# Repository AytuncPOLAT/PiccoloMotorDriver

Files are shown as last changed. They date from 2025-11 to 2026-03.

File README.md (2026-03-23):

# PiccoloMotorDriver

Yet another open source servo motor driver designed using Kicad, based on STM32H723 MCU and DRV8316 integrated 3-phase motor driver.

Firmware can be found here (under development): https://github.com/AytuncPOLAT/PiccoloMotorDriverFw

All the subsystems have been tested

| Subsystem | Test Status |
| --- | --- |
| FDCAN | :heavy_check_mark: |
| RS485 | :heavy_check_mark: |
| USB | :heavy_check_mark: |
| Debug UART | :clock9: |
| SWD | :heavy_check_mark: |
| Ext. Encoder  | :heavy_check_mark: |
| Ext. Analog | :heavy_check_mark: |
| LEDs | :heavy_check_mark: |
| J9 GPIOs | :clock9: |
| DRV8316 | :heavy_check_mark: |

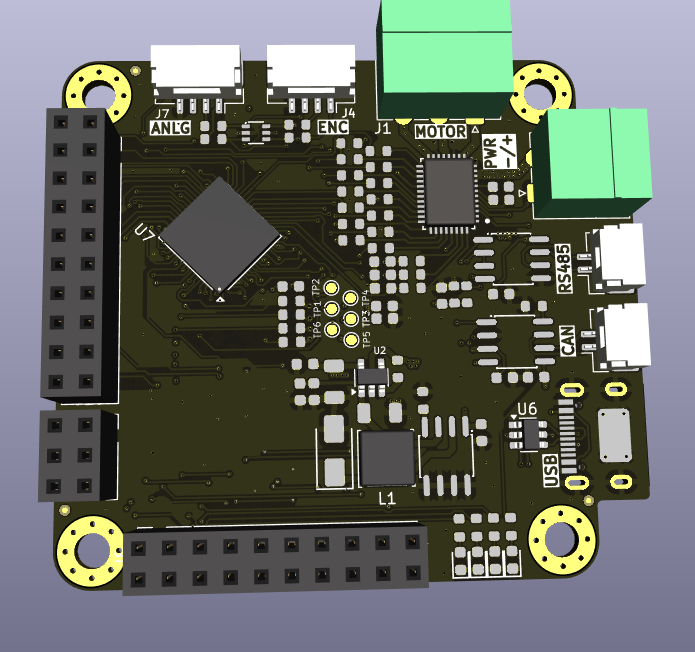
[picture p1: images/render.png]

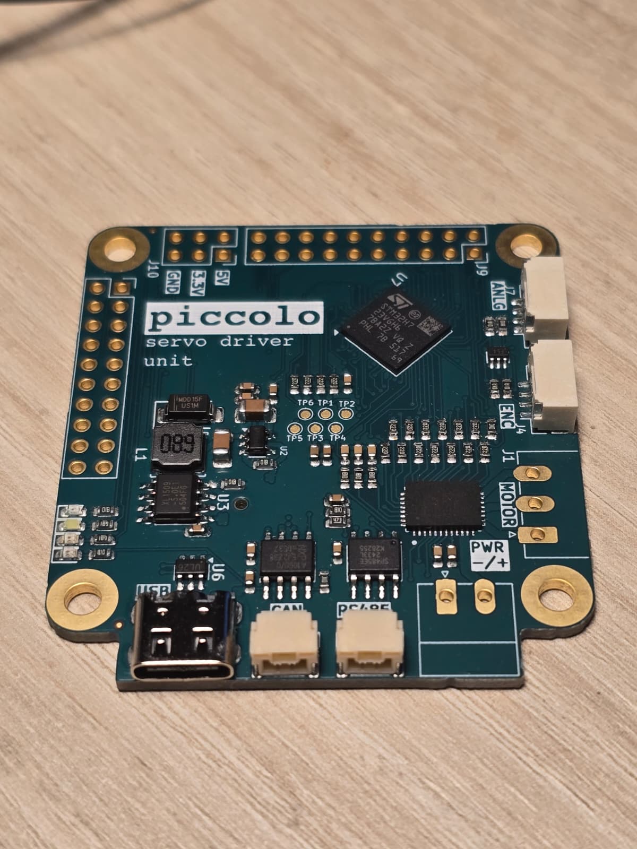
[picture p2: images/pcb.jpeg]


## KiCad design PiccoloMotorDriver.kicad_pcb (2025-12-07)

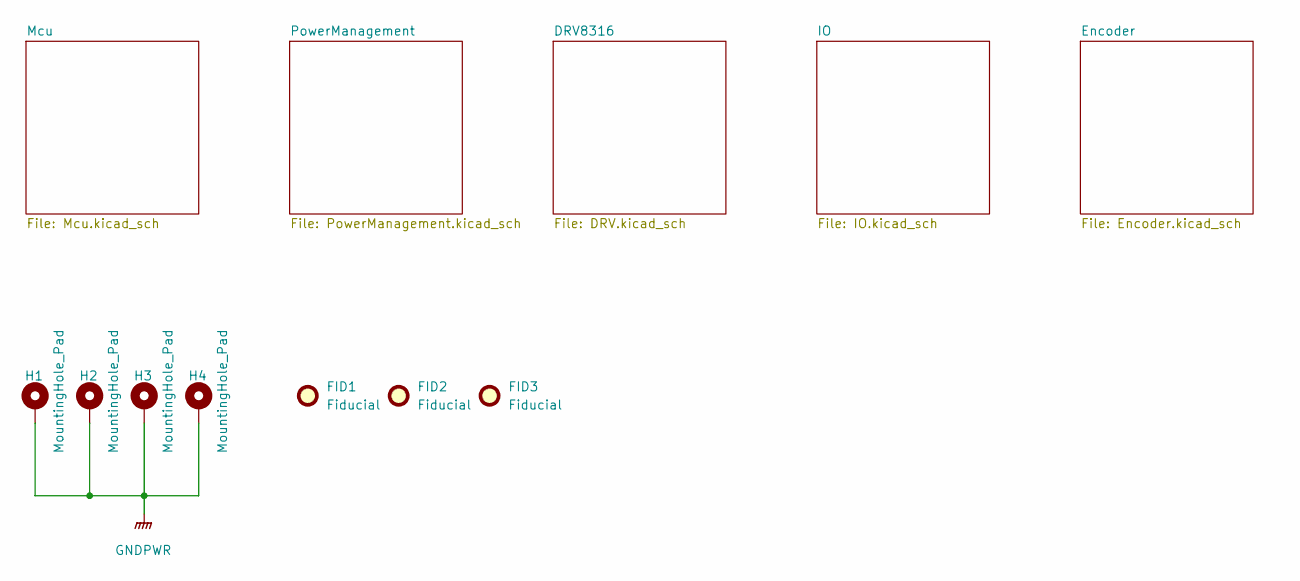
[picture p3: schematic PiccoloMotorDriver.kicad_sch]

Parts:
FID1, FID2, FID3: Fiducial; Fiducial_0.5mm_Mask1mm
H1, H2, H3, H4: MountingHole_Pad; MountingHole_3.2mm_M3_Pad_Via

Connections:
GND: H1.1, H2.1, H3.1, H4.1; also elsewhere on the board

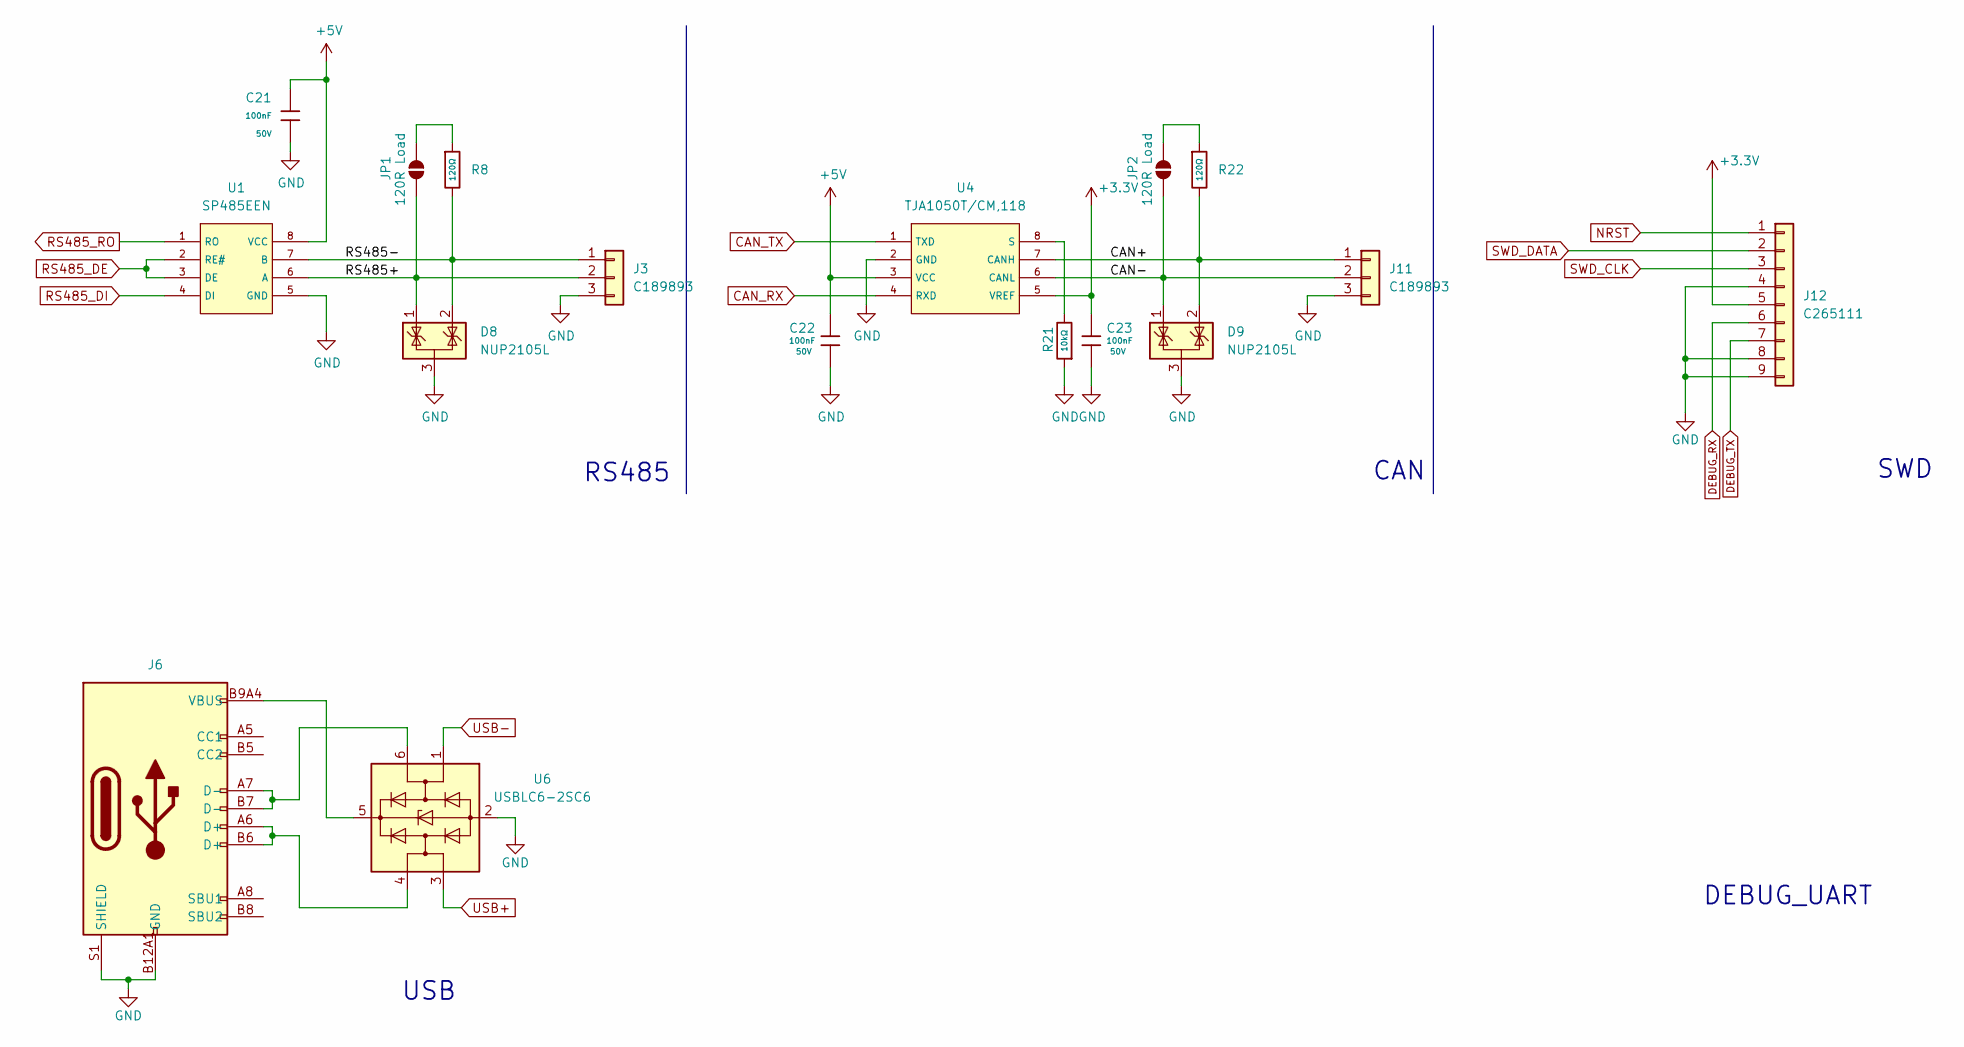
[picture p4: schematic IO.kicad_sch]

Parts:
C21, C22, C23: 100nF; C_0603; Voltage Rated 50V; Tolerance ±10%; Part CC0603KRX7R9BB104; LCSC C14663
D8, D9: NUP2105L; SOT-23
J3, J11: C189893; JST_GH_SM02B-GHS-TB_1x02-1MP_P1.25mm_Horizontal
J6: Connector, USB-TYPE-C-16P; TYPE-C-SMD_HX-TYPE-C-16PIN; LCSC C2927039
J12: C265111; JST_GH_SM08B-GHS-TB_1x08-1MP_P1.25mm_Horizontal
JP1, JP2: 120R Load; SolderJumper-2_P1.3mm_Open_TrianglePad1.0x1.5mm
R8, R22: 120Ω; R_0603; Overload Voltage (Max) 75V; Tolerance ±1%; Part 0603WAF1200T5E; LCSC C22787
R21: 10kΩ; R_0603; Overload Voltage (Max) 75V; Tolerance ±1%; Part 0603WAF1002T5E; LCSC C25804
U1: SP485EEN; SOIC-8_L5.0-W4.0-P1.27-LS6.0-BL; Supply Voltage 4.75V~5.25V; Part SP485EEN-L/TR; LCSC C6855
U4: TJA1050T/CM,118; SOIC-8_L5.0-W4.0-P1.27-LS6.0-BL; Supply Voltage 4.75V~5.25V; Part TJA1050T/CM,118; LCSC C6952
U6: USBLC6-2SC6; SOT-23-6

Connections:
+3.3V: C23.1, J12.5, U4.5 (VREF); also elsewhere on the board
+5V: C21.1, C22.1, U1.8 (VCC), U4.3 (VCC); also elsewhere on the board
/IO/CAN+: D9.2 (K), J11.1, R22.2, U4.7 (CANH)
/IO/CAN-: D9.1 (K), J11.2, JP2.1 (A), U4.6 (CANL)
/IO/RS485+: D8.1 (K), J3.2, JP1.1 (A), U1.6 (A)
/IO/RS485-: D8.2 (K), J3.1, R8.2, U1.7 (B)
CAN_RX: U4.4 (RXD); also elsewhere on the board
CAN_TX: U4.1 (TXD); also elsewhere on the board
DEBUG_RX: J12.6; also elsewhere on the board
DEBUG_TX: J12.7; also elsewhere on the board
GND: C21.2, C22.2, C23.2, D8.3 (A), D9.3 (A), J3.3, J6.A12B1 (GND), J6.B12A1 (GND), J6.S1 (SHIELD), J11.3, J12.4, J12.8, J12.9, R21.1, U1.5 (GND), U4.2 (GND), U6.2 (GND); also elsewhere on the board
NRST: J12.1; also elsewhere on the board
unnamed: J6.A6 (D+), J6.B6 (D+), U6.4 (I/O2)
unnamed: J6.A7 (D-), J6.B7 (D-), U6.6 (I/O1)
unnamed: JP1.2 (B), R8.1
unnamed: JP2.2 (B), R22.1
unnamed: R21.2, U4.8 (S)
unnamed: J6.A9B4 (VBUS), J6.B9A4 (VBUS), U6.5 (VBUS)
RS485_DE: U1.2 (RE#), U1.3 (DE); also elsewhere on the board
RS485_DI: U1.4 (DI); also elsewhere on the board
RS485_RO: U1.1 (RO); also elsewhere on the board
SWD_CLK: J12.3; also elsewhere on the board
SWD_DATA: J12.2; also elsewhere on the board
USB+: U6.3 (I/O2); also elsewhere on the board
USB-: U6.1 (I/O1); also elsewhere on the board

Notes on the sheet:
RS485
USB
DEBUG_UART
SWD
CAN

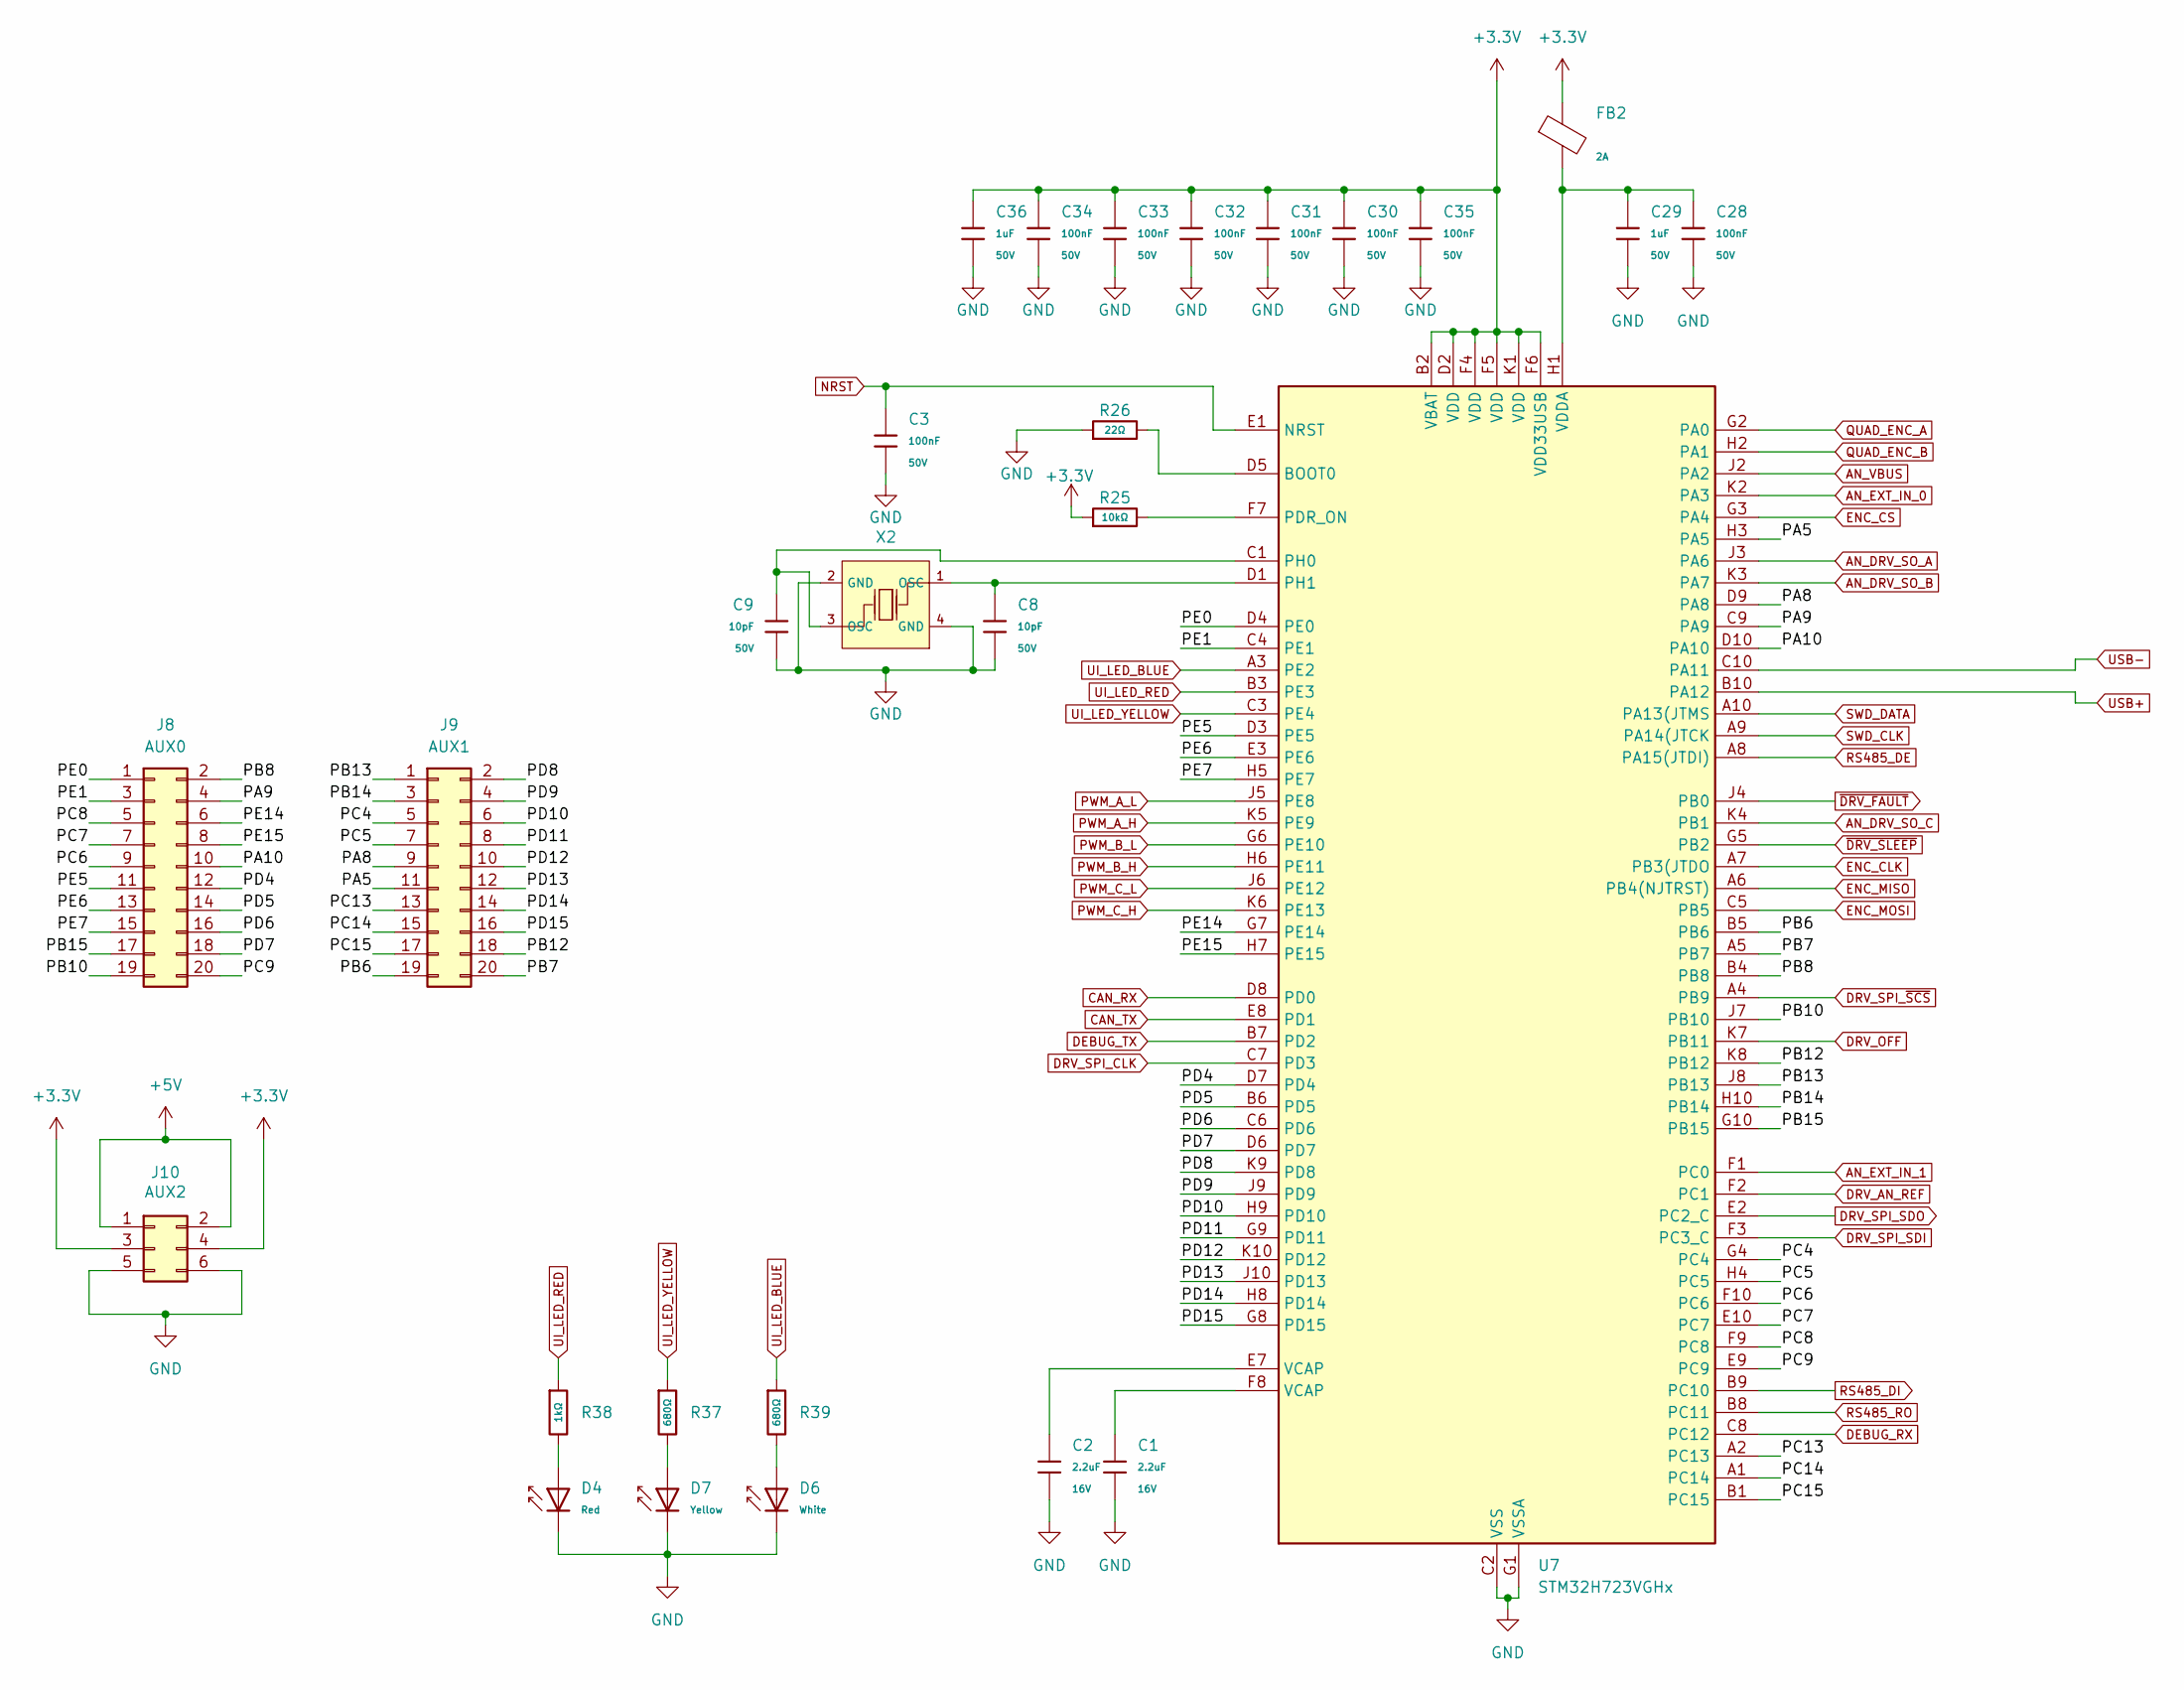
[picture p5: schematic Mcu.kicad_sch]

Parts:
C1, C2: 2.2uF; C_0603; Voltage Rated 16V; Tolerance ±10%; Part CL10A225KO8NNNC; LCSC C23630
C3, C28, C30, C31, C32, C33, C34, C35: 100nF; C_0603; Voltage Rated 50V; Tolerance ±10%; Part CC0603KRX7R9BB104; LCSC C14663
C8, C9: 10pF; C_0603; Voltage Rated 50V; Tolerance ±5%; Part CL10C100JB8NNNC; LCSC C1634
C29, C36: 1uF; C_0603; Voltage Rated 50V; Tolerance ±10%; Part CL10A105KB8NNNC; LCSC C15849
D4: Red; D_0603; Part KT-0603R; LCSC C2286
D6: White; D_0603; Part KT-0603W; LCSC C2290
D7: Yellow; D_0603; Forward Voltage (VF) 1.6V~2.6V; Part NCD0603Y2; LCSC C89811
FB2: FB_0603; Current Rating 2A; Tolerance ±25%; Part BLM18PG121SN1D; LCSC C14709
J8: AUX0; PinSocket_2x10_P2.54mm_Vertical
J9: AUX1; PinSocket_2x10_P2.54mm_Vertical
J10: AUX2; PinSocket_2x03_P2.54mm_Vertical
R25: 10kΩ; R_0603; Overload Voltage (Max) 75V; Tolerance ±1%; Part 0603WAF1002T5E; LCSC C25804
R26: 22Ω; R_0603; Overload Voltage (Max) 75V; Tolerance ±1%; Part 0603WAF220JT5E; LCSC C23345
R37, R39: 680Ω; R_0603; Overload Voltage (Max) 75V; Tolerance ±1%; Part 0603WAF6800T5E; LCSC C23228
R38: 1kΩ; R_0603; Overload Voltage (Max) 75V; Tolerance ±1%; Part 0603WAF1001T5E; LCSC C21190
U7: STM32H723VGHx; TFBGA-100_8x8mm_Layout10x10_P0.8mm
X2: X322516MLB4SI; OSC-SMD_4P-L3.2-W2.5-BL; Frequency Tolerance ±10ppm; Part X322516MLB4SI; LCSC C13738

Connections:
+3.3V: C30.1, C31.1, C32.1, C33.1, C34.1, C35.1, C36.1, FB2.1, J10.3, J10.4, R25.1, U7.B2 (VBAT), U7.D2 (VDD), U7.F4 (VDD), U7.F5 (VDD), U7.F6 (VDD33USB), U7.K1 (VDD); also elsewhere on the board
+5V: J10.1, J10.2; also elsewhere on the board
/Mcu/PA5: J9.11, U7.H3 (PA5)
/Mcu/PA8: J9.9, U7.D9 (PA8)
/Mcu/PA9: J8.4, U7.C9 (PA9)
/Mcu/PA10: J8.10, U7.D10 (PA10)
/Mcu/PB6: J9.19, U7.B5 (PB6)
/Mcu/PB7: J9.20, U7.A5 (PB7)
/Mcu/PB8: J8.2, U7.B4 (PB8)
/Mcu/PB10: J8.19, U7.J7 (PB10)
/Mcu/PB12: J9.18, U7.K8 (PB12)
/Mcu/PB13: J9.1, U7.J8 (PB13)
/Mcu/PB14: J9.3, U7.H10 (PB14)
/Mcu/PB15: J8.17, U7.G10 (PB15)
/Mcu/PC4: J9.5, U7.G4 (PC4)
/Mcu/PC5: J9.7, U7.H4 (PC5)
/Mcu/PC6: J8.9, U7.F10 (PC6)
/Mcu/PC7: J8.7, U7.E10 (PC7)
/Mcu/PC8: J8.5, U7.F9 (PC8)
/Mcu/PC9: J8.20, U7.E9 (PC9)
/Mcu/PC13: J9.13, U7.A2 (PC13)
/Mcu/PC14: J9.15, U7.A1 (PC14)
/Mcu/PC15: J9.17, U7.B1 (PC15)
/Mcu/PD4: J8.12, U7.D7 (PD4)
/Mcu/PD5: J8.14, U7.B6 (PD5)
/Mcu/PD6: J8.16, U7.C6 (PD6)
/Mcu/PD7: J8.18, U7.D6 (PD7)
/Mcu/PD8: J9.2, U7.K9 (PD8)
/Mcu/PD9: J9.4, U7.J9 (PD9)
/Mcu/PD10: J9.6, U7.H9 (PD10)
/Mcu/PD11: J9.8, U7.G9 (PD11)
/Mcu/PD12: J9.10, U7.K10 (PD12)
/Mcu/PD13: J9.12, U7.J10 (PD13)
/Mcu/PD14: J9.14, U7.H8 (PD14)
/Mcu/PD15: J9.16, U7.G8 (PD15)
/Mcu/PE0: J8.1, U7.D4 (PE0)
/Mcu/PE1: J8.3, U7.C4 (PE1)
/Mcu/PE5: J8.11, U7.D3 (PE5)
/Mcu/PE6: J8.13, U7.E3 (PE6)
/Mcu/PE7: J8.15, U7.H5 (PE7)
/Mcu/PE14: J8.6, U7.G7 (PE14)
/Mcu/PE15: J8.8, U7.H7 (PE15)
AN_DRV_SO_A: U7.J3 (PA6); also elsewhere on the board
AN_DRV_SO_B: U7.K3 (PA7); also elsewhere on the board
AN_DRV_SO_C: U7.K4 (PB1); also elsewhere on the board
AN_EXT_IN_0: U7.K2 (PA3); also elsewhere on the board
AN_EXT_IN_1: U7.F1 (PC0); also elsewhere on the board
AN_VBUS: U7.J2 (PA2); also elsewhere on the board
CAN_RX: U7.D8 (PD0); also elsewhere on the board
CAN_TX: U7.E8 (PD1); also elsewhere on the board
DEBUG_RX: U7.C8 (PC12); also elsewhere on the board
DEBUG_TX: U7.B7 (PD2); also elsewhere on the board
DRV_AN_REF: U7.F2 (PC1); also elsewhere on the board
DRV_OFF: U7.K7 (PB11); also elsewhere on the board
DRV_SPI_CLK: U7.C7 (PD3); also elsewhere on the board
DRV_SPI_SDI: U7.F3 (PC3_C); also elsewhere on the board
DRV_SPI_SDO: U7.E2 (PC2_C); also elsewhere on the board
DRV_SPI_~SCS: U7.A4 (PB9); also elsewhere on the board
ENC_CLK: U7.A7 (PB3(JTDO); also elsewhere on the board
ENC_CS: U7.G3 (PA4); also elsewhere on the board
ENC_MISO: U7.A6 (PB4(NJTRST)); also elsewhere on the board
ENC_MOSI: U7.C5 (PB5); also elsewhere on the board
GND: C1.2, C2.2, C3.2, C8.2, C9.2, C28.2, C29.2, C30.2, C31.2, C32.2, C33.2, C34.2, C35.2, C36.2, D4.1, D6.1, D7.1, J10.5, J10.6, R26.1, U7.C2 (VSS), U7.E4 (VSS), U7.E5 (VSS), U7.E6 (VSS), U7.G1 (VSSA), U7.J1 (VSS), X2.2 (GND), X2.4 (GND); also elsewhere on the board
NRST: C3.1, U7.E1 (NRST); also elsewhere on the board
unnamed: C1.1, U7.F8 (VCAP)
unnamed: C2.1, U7.E7 (VCAP)
unnamed: D4.2, R38.2
unnamed: D6.2, R39.2
unnamed: D7.2, R37.2
unnamed: R26.2, U7.D5 (BOOT0)
unnamed: R25.2, U7.F7 (PDR_ON)
unnamed: C9.1, U7.C1 (PH0), X2.3 (OSC)
unnamed: C8.1, U7.D1 (PH1), X2.1 (OSC)
unnamed: C28.1, C29.1, FB2.2, U7.H1 (VDDA)
PWM_A_H: U7.K5 (PE9); also elsewhere on the board
PWM_A_L: U7.J5 (PE8); also elsewhere on the board
PWM_B_H: U7.H6 (PE11); also elsewhere on the board
PWM_B_L: U7.G6 (PE10); also elsewhere on the board
PWM_C_H: U7.K6 (PE13); also elsewhere on the board
PWM_C_L: U7.J6 (PE12); also elsewhere on the board
QUAD_ENC_A: U7.G2 (PA0); also elsewhere on the board
QUAD_ENC_B: U7.H2 (PA1); also elsewhere on the board
RS485_DE: U7.A8 (PA15(JTDI)); also elsewhere on the board
RS485_DI: U7.B9 (PC10); also elsewhere on the board
RS485_RO: U7.B8 (PC11); also elsewhere on the board
SWD_CLK: U7.A9 (PA14(JTCK); also elsewhere on the board
SWD_DATA: U7.A10 (PA13(JTMS); also elsewhere on the board
UI_LED_BLUE: R39.1, U7.A3 (PE2)
UI_LED_RED: R38.1, U7.B3 (PE3)
UI_LED_YELLOW: R37.1, U7.C3 (PE4)
USB+: U7.B10 (PA12); also elsewhere on the board
USB-: U7.C10 (PA11); also elsewhere on the board
~DRV_FAULT: U7.J4 (PB0); also elsewhere on the board
~DRV_SLEEP: U7.G5 (PB2); also elsewhere on the board

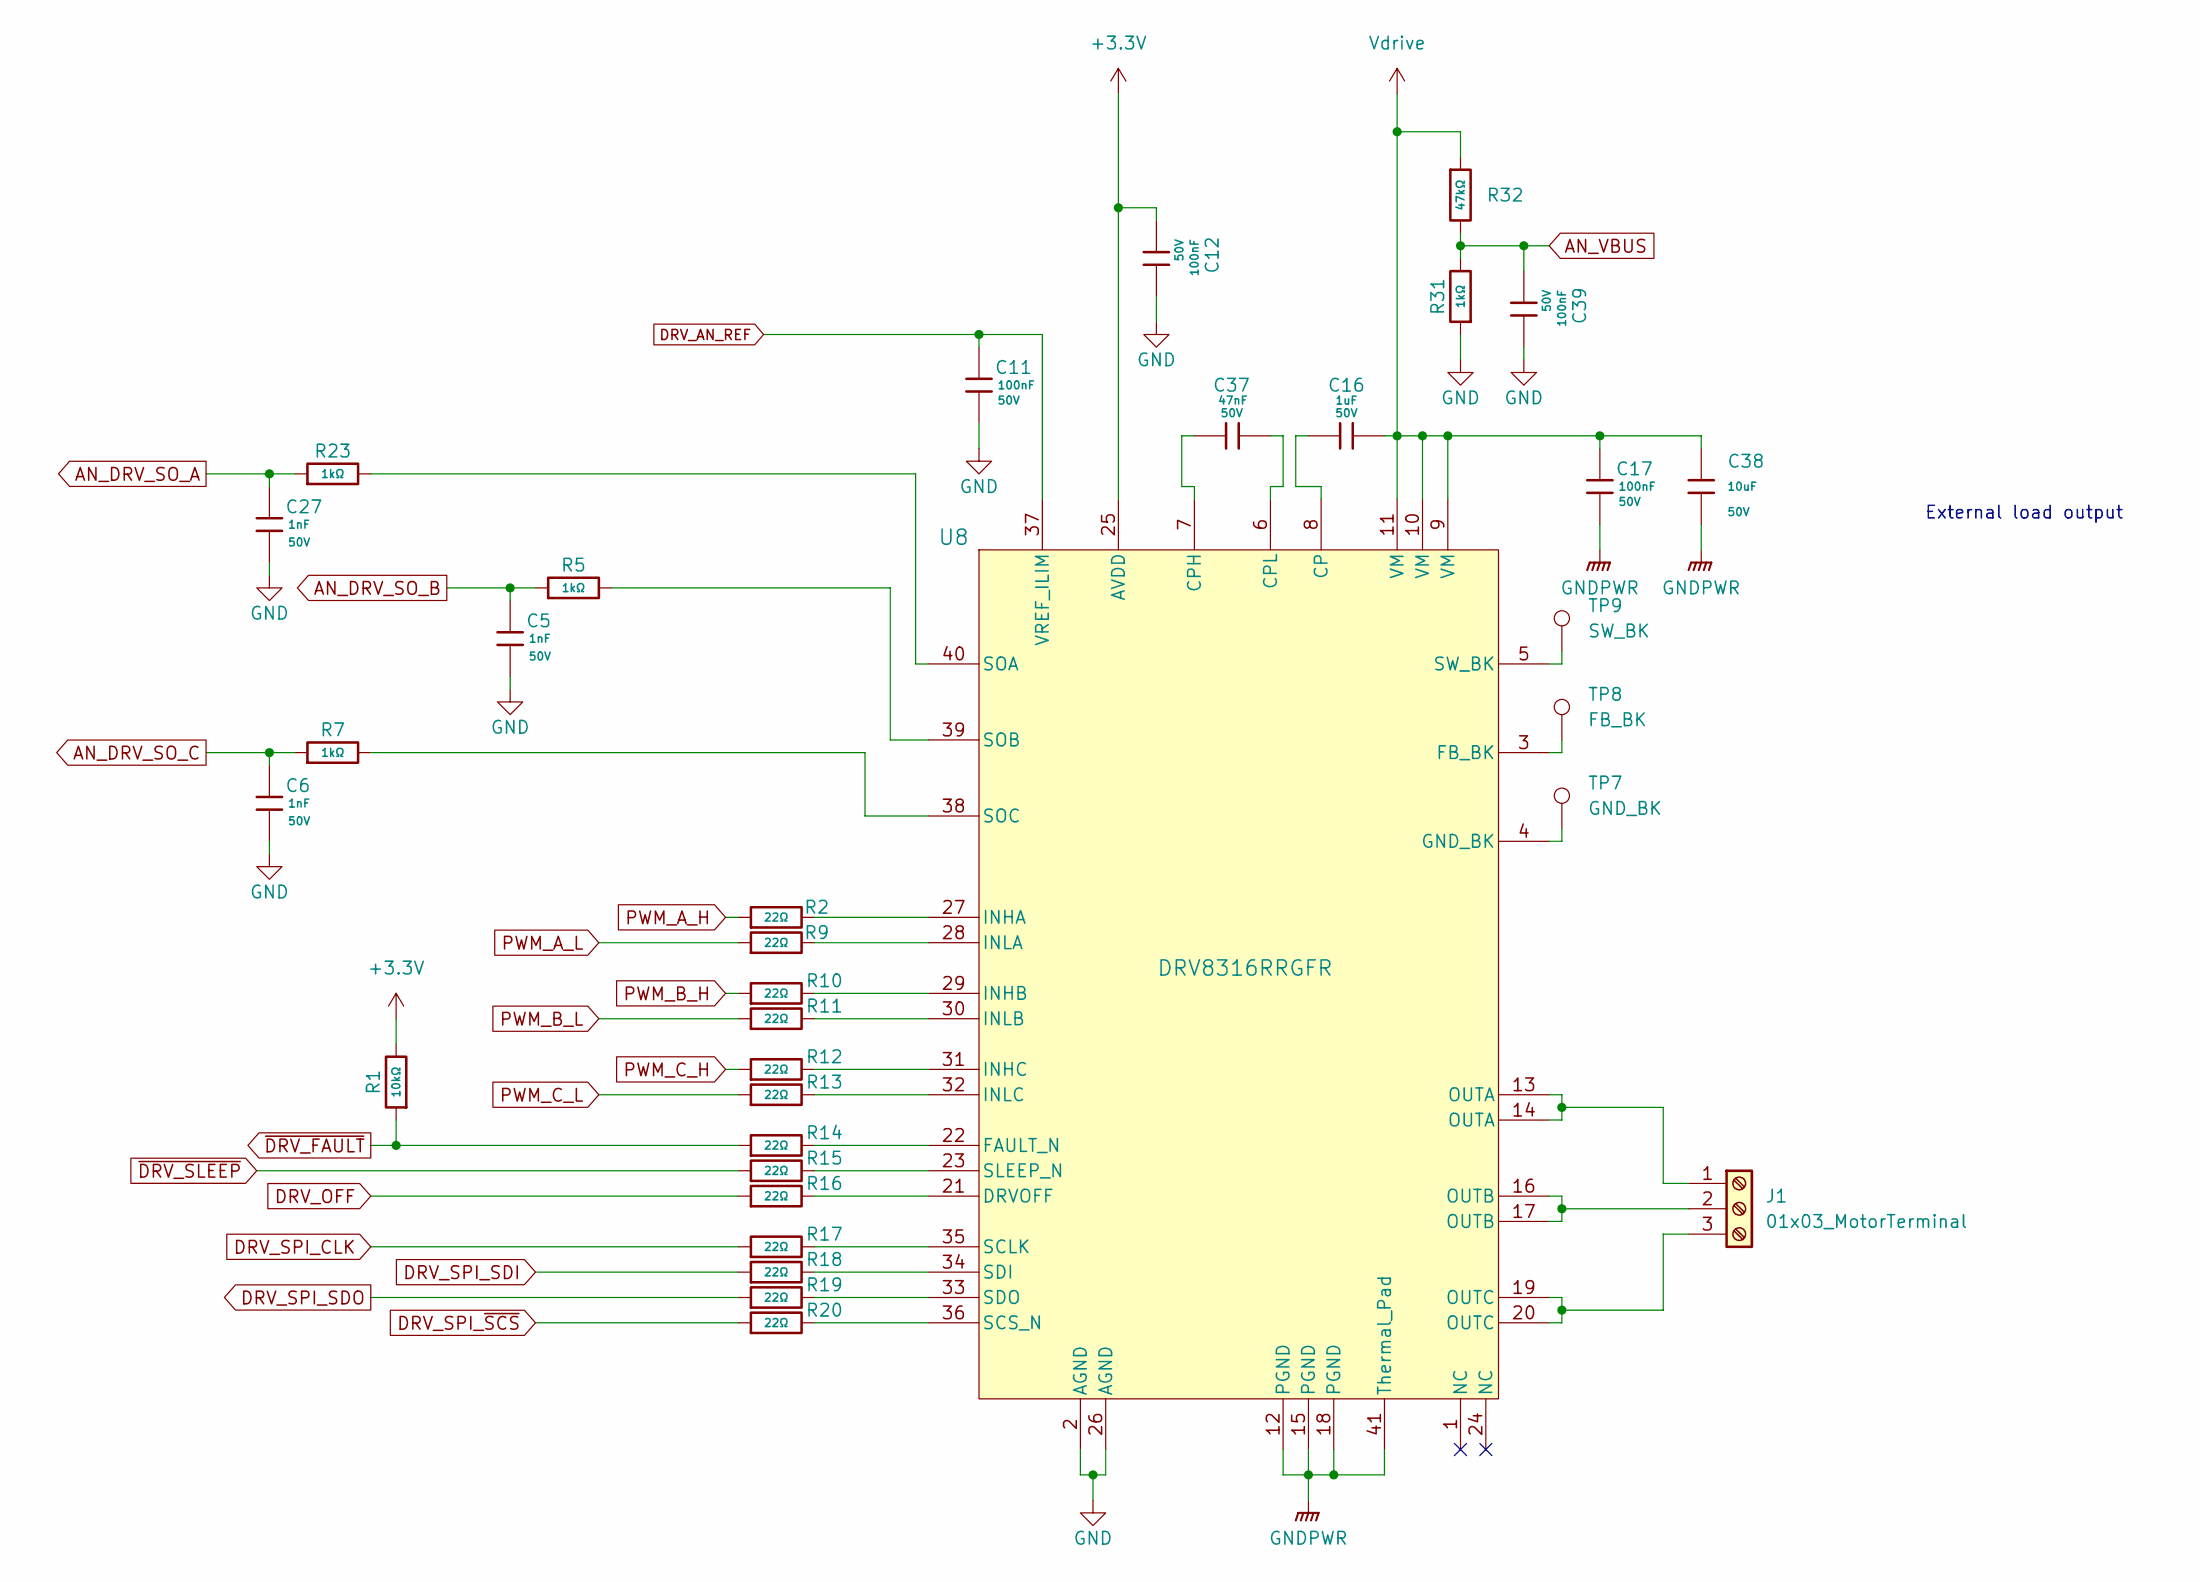
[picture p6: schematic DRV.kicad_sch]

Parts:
C5, C6, C27: 1nF; C_0603; Voltage Rated 50V; Tolerance ±10%; Part CL10B102KB8NNNC; LCSC C1588
C11, C12, C17, C39: 100nF; C_0603; Voltage Rated 50V; Tolerance ±10%; Part CC0603KRX7R9BB104; LCSC C14663
C16: 1uF; C_0603; Voltage Rated 50V; Tolerance ±10%; Part CL10A105KB8NNNC; LCSC C15849
C37: 47nF; C_0603; Voltage Rated 50V; Tolerance ±10%; Part CL10B473KB8NNNC; LCSC C1622
C38: 10uF; C_1206; Voltage Rated 50V; Tolerance ±10%; Part CL31A106KBHNNNE; LCSC C13585
J1: 01x03_MotorTerminal; PhoenixContact_MC_1,5_3-G-3.5_1x03_P3.50mm_Horizontal
R1: 10kΩ; R_0603; Overload Voltage (Max) 75V; Tolerance ±1%; Part 0603WAF1002T5E; LCSC C25804
R2, R9, R10, R11, R12, R13, R14, R15, R16, R17, R18, R19, R20: 22Ω; R_0603; Overload Voltage (Max) 75V; Tolerance ±1%; Part 0603WAF220JT5E; LCSC C23345
R5, R7, R23, R31: 1kΩ; R_0603; Overload Voltage (Max) 75V; Tolerance ±1%; Part 0603WAF1001T5E; LCSC C21190
R32: 47kΩ; R_0603; Overload Voltage (Max) 75V; Tolerance ±1%; Part 0603WAF4702T5E; LCSC C25819
TP7: GND_BK; TestPoint_Pad_D1.0mm
TP8: FB_BK; TestPoint_Pad_D1.0mm
TP9: SW_BK; TestPoint_Pad_D1.0mm
U8: DRV8316RRGFR; RGF0040E-IPC_A

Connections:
+3.3V: C12.1, R1.2, U8.25 (AVDD); also elsewhere on the board
AN_DRV_SO_A: C27.1, R23.1; also elsewhere on the board
AN_DRV_SO_B: C5.1, R5.1; also elsewhere on the board
AN_DRV_SO_C: C6.1, R7.1; also elsewhere on the board
AN_VBUS: C39.1, R31.2, R32.2; also elsewhere on the board
DRV_AN_REF: C11.1, U8.37 (VREF_ILIM); also elsewhere on the board
DRV_OFF: R16.1; also elsewhere on the board
DRV_SPI_CLK: R17.1; also elsewhere on the board
DRV_SPI_SDI: R18.1; also elsewhere on the board
DRV_SPI_SDO: R19.1; also elsewhere on the board
DRV_SPI_~SCS: R20.1; also elsewhere on the board
GND: C5.2, C6.2, C11.2, C12.2, C17.2, C27.2, C38.2, C39.2, R31.1, U8.2 (AGND), U8.12 (PGND), U8.15 (PGND), U8.18 (PGND), U8.26 (AGND), U8.41 (Thermal_Pad); also elsewhere on the board
unnamed: J1.1, U8.13 (OUTA), U8.14 (OUTA)
unnamed: J1.2, U8.16 (OUTB), U8.17 (OUTB)
unnamed: J1.3, U8.19 (OUTC), U8.20 (OUTC)
unnamed: C16.1, U8.8 (CP)
unnamed: C37.1, U8.7 (CPH)
unnamed: C37.2, U8.6 (CPL)
unnamed: R16.2, U8.21 (DRVOFF)
unnamed: R14.2, U8.22 (FAULT_N)
unnamed: TP8.1, U8.3 (FB_BK)
unnamed: TP7.1, U8.4 (GND_BK)
unnamed: R2.2, U8.27 (INHA)
unnamed: R10.2, U8.29 (INHB)
unnamed: R12.2, U8.31 (INHC)
unnamed: R9.2, U8.28 (INLA)
unnamed: R11.2, U8.30 (INLB)
unnamed: R13.2, U8.32 (INLC)
unnamed: R17.2, U8.35 (SCLK)
unnamed: R20.2, U8.36 (SCS_N)
unnamed: R18.2, U8.34 (SDI)
unnamed: R19.2, U8.33 (SDO)
unnamed: R15.2, U8.23 (SLEEP_N)
unnamed: R23.2, U8.40 (SOA)
unnamed: R5.2, U8.39 (SOB)
unnamed: R7.2, U8.38 (SOC)
unnamed: TP9.1, U8.5 (SW_BK)
PWM_A_H: R2.1; also elsewhere on the board
PWM_A_L: R9.1; also elsewhere on the board
PWM_B_H: R10.1; also elsewhere on the board
PWM_B_L: R11.1; also elsewhere on the board
PWM_C_H: R12.1; also elsewhere on the board
PWM_C_L: R13.1; also elsewhere on the board
Vdrive: C16.2, C17.1, C38.1, R32.1, U8.9 (VM), U8.10 (VM), U8.11 (VM); also elsewhere on the board
~DRV_FAULT: R1.1, R14.1; also elsewhere on the board
~DRV_SLEEP: R15.1; also elsewhere on the board

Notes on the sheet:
External load output

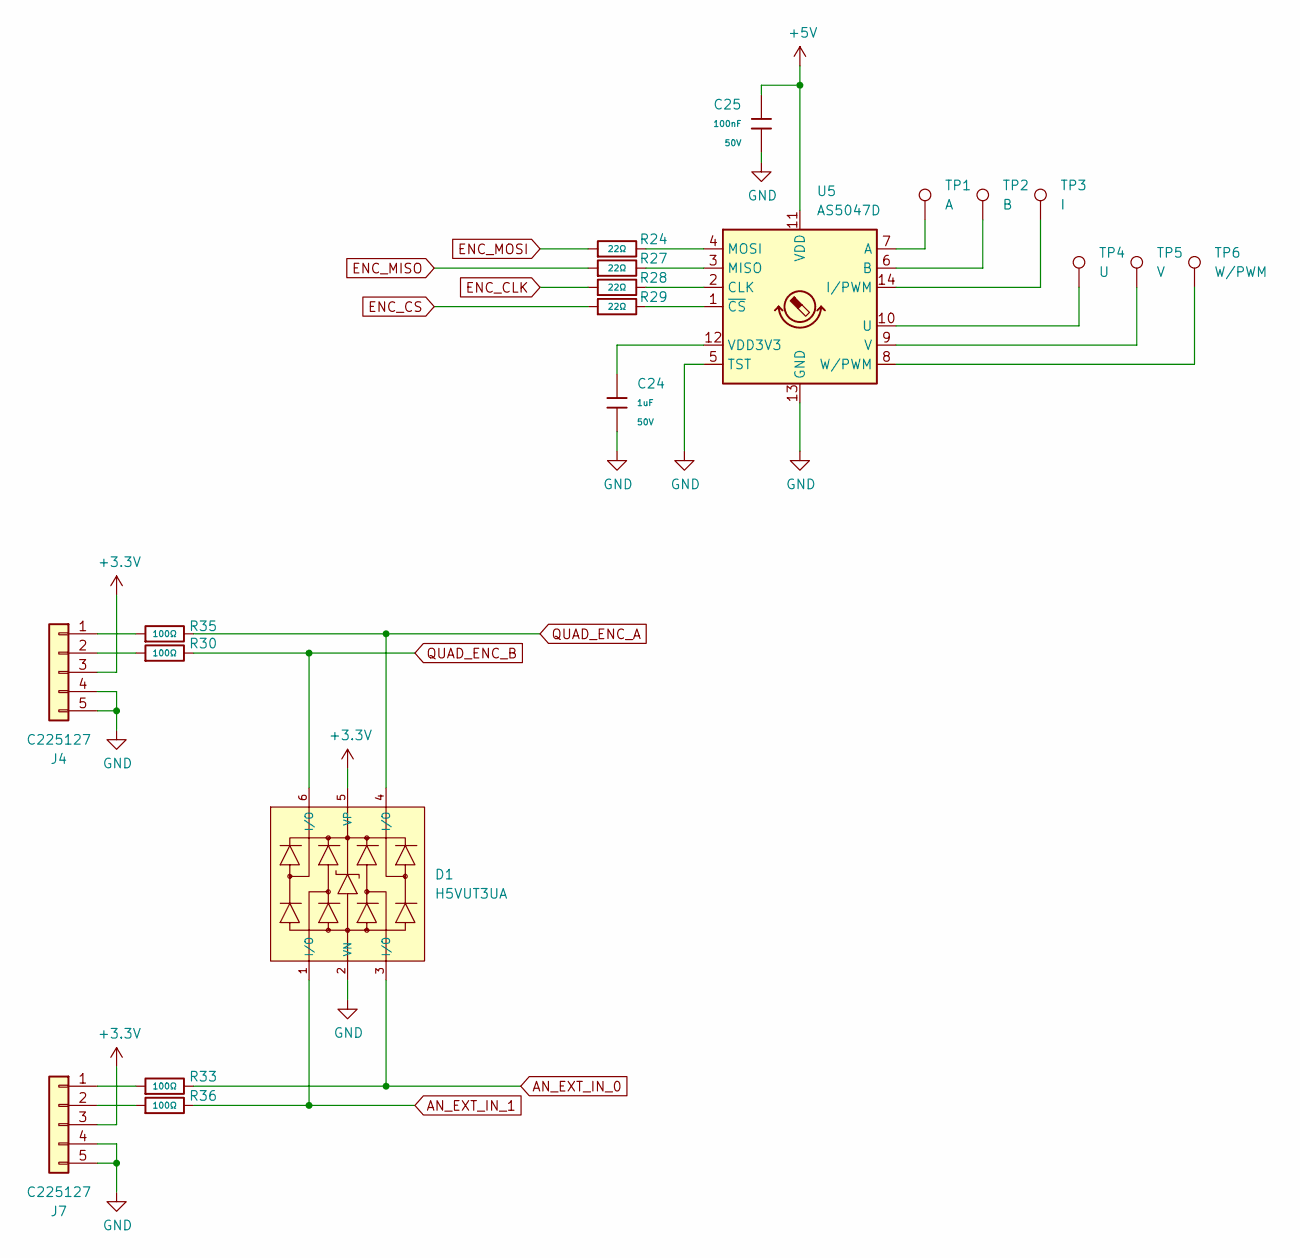
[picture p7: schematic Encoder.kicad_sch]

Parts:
C24: 1uF; C_0603; Voltage Rated 50V; Tolerance ±10%; Part CL10A105KB8NNNC; LCSC C15849
C25: 100nF; C_0603; Voltage Rated 50V; Tolerance ±10%; Part CC0603KRX7R9BB104; LCSC C14663
D1: H5VUT3UA; SOT-363_L2.1-W1.3-P0.65-LS2.2-BL; Part H5VUT3UA; LCSC C20615830
J4, J7: C225127; JST_GH_SM04B-GHS-TB_1x04-1MP_P1.25mm_Horizontal
R24, R27, R28, R29: 22Ω; R_0603; Overload Voltage (Max) 75V; Tolerance ±1%; Part 0603WAF220JT5E; LCSC C23345
R30, R33, R35, R36: 100Ω; R_0603; Overload Voltage (Max) 75V; Tolerance ±1%; Part 0603WAF1000T5E; LCSC C22775
TP1: A; TestPoint_Pad_D1.0mm
TP2: B; TestPoint_Pad_D1.0mm
TP3: I; TestPoint_Pad_D1.0mm
TP4: U; TestPoint_Pad_D1.0mm
TP5: V; TestPoint_Pad_D1.0mm
TP6: W/PWM; TestPoint_Pad_D1.0mm
U5: AS5047D; TSSOP-14_4.4x5mm_P0.65mm

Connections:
+3.3V: D1.5 (VP), J4.3, J7.3; also elsewhere on the board
+5V: C25.1, U5.11 (VDD); also elsewhere on the board
AN_EXT_IN_0: D1.3 (I/O), R33.2; also elsewhere on the board
AN_EXT_IN_1: D1.1 (I/O), R36.2; also elsewhere on the board
ENC_CLK: R28.1; also elsewhere on the board
ENC_CS: R29.1; also elsewhere on the board
ENC_MISO: R27.1; also elsewhere on the board
ENC_MOSI: R24.1; also elsewhere on the board
GND: C24.2, C25.2, D1.2 (VN), J4.4, J4.5, J7.4, J7.5, U5.5 (TST), U5.13 (GND); also elsewhere on the board
unnamed: J4.1, R35.1
unnamed: J4.2, R30.1
unnamed: J7.1, R33.1
unnamed: J7.2, R36.1
unnamed: TP1.1, U5.7 (A)
unnamed: TP2.1, U5.6 (B)
unnamed: R28.2, U5.2 (CLK)
unnamed: TP3.1, U5.14 (I/PWM)
unnamed: R27.2, U5.3 (MISO)
unnamed: R24.2, U5.4 (MOSI)
unnamed: TP4.1, U5.10 (U)
unnamed: TP5.1, U5.9 (V)
unnamed: C24.1, U5.12 (VDD3V3)
unnamed: TP6.1, U5.8 (W/PWM)
unnamed: R29.2, U5.1 (~CS)
QUAD_ENC_A: D1.4 (I/O), R35.2; also elsewhere on the board
QUAD_ENC_B: D1.6 (I/O), R30.2; also elsewhere on the board

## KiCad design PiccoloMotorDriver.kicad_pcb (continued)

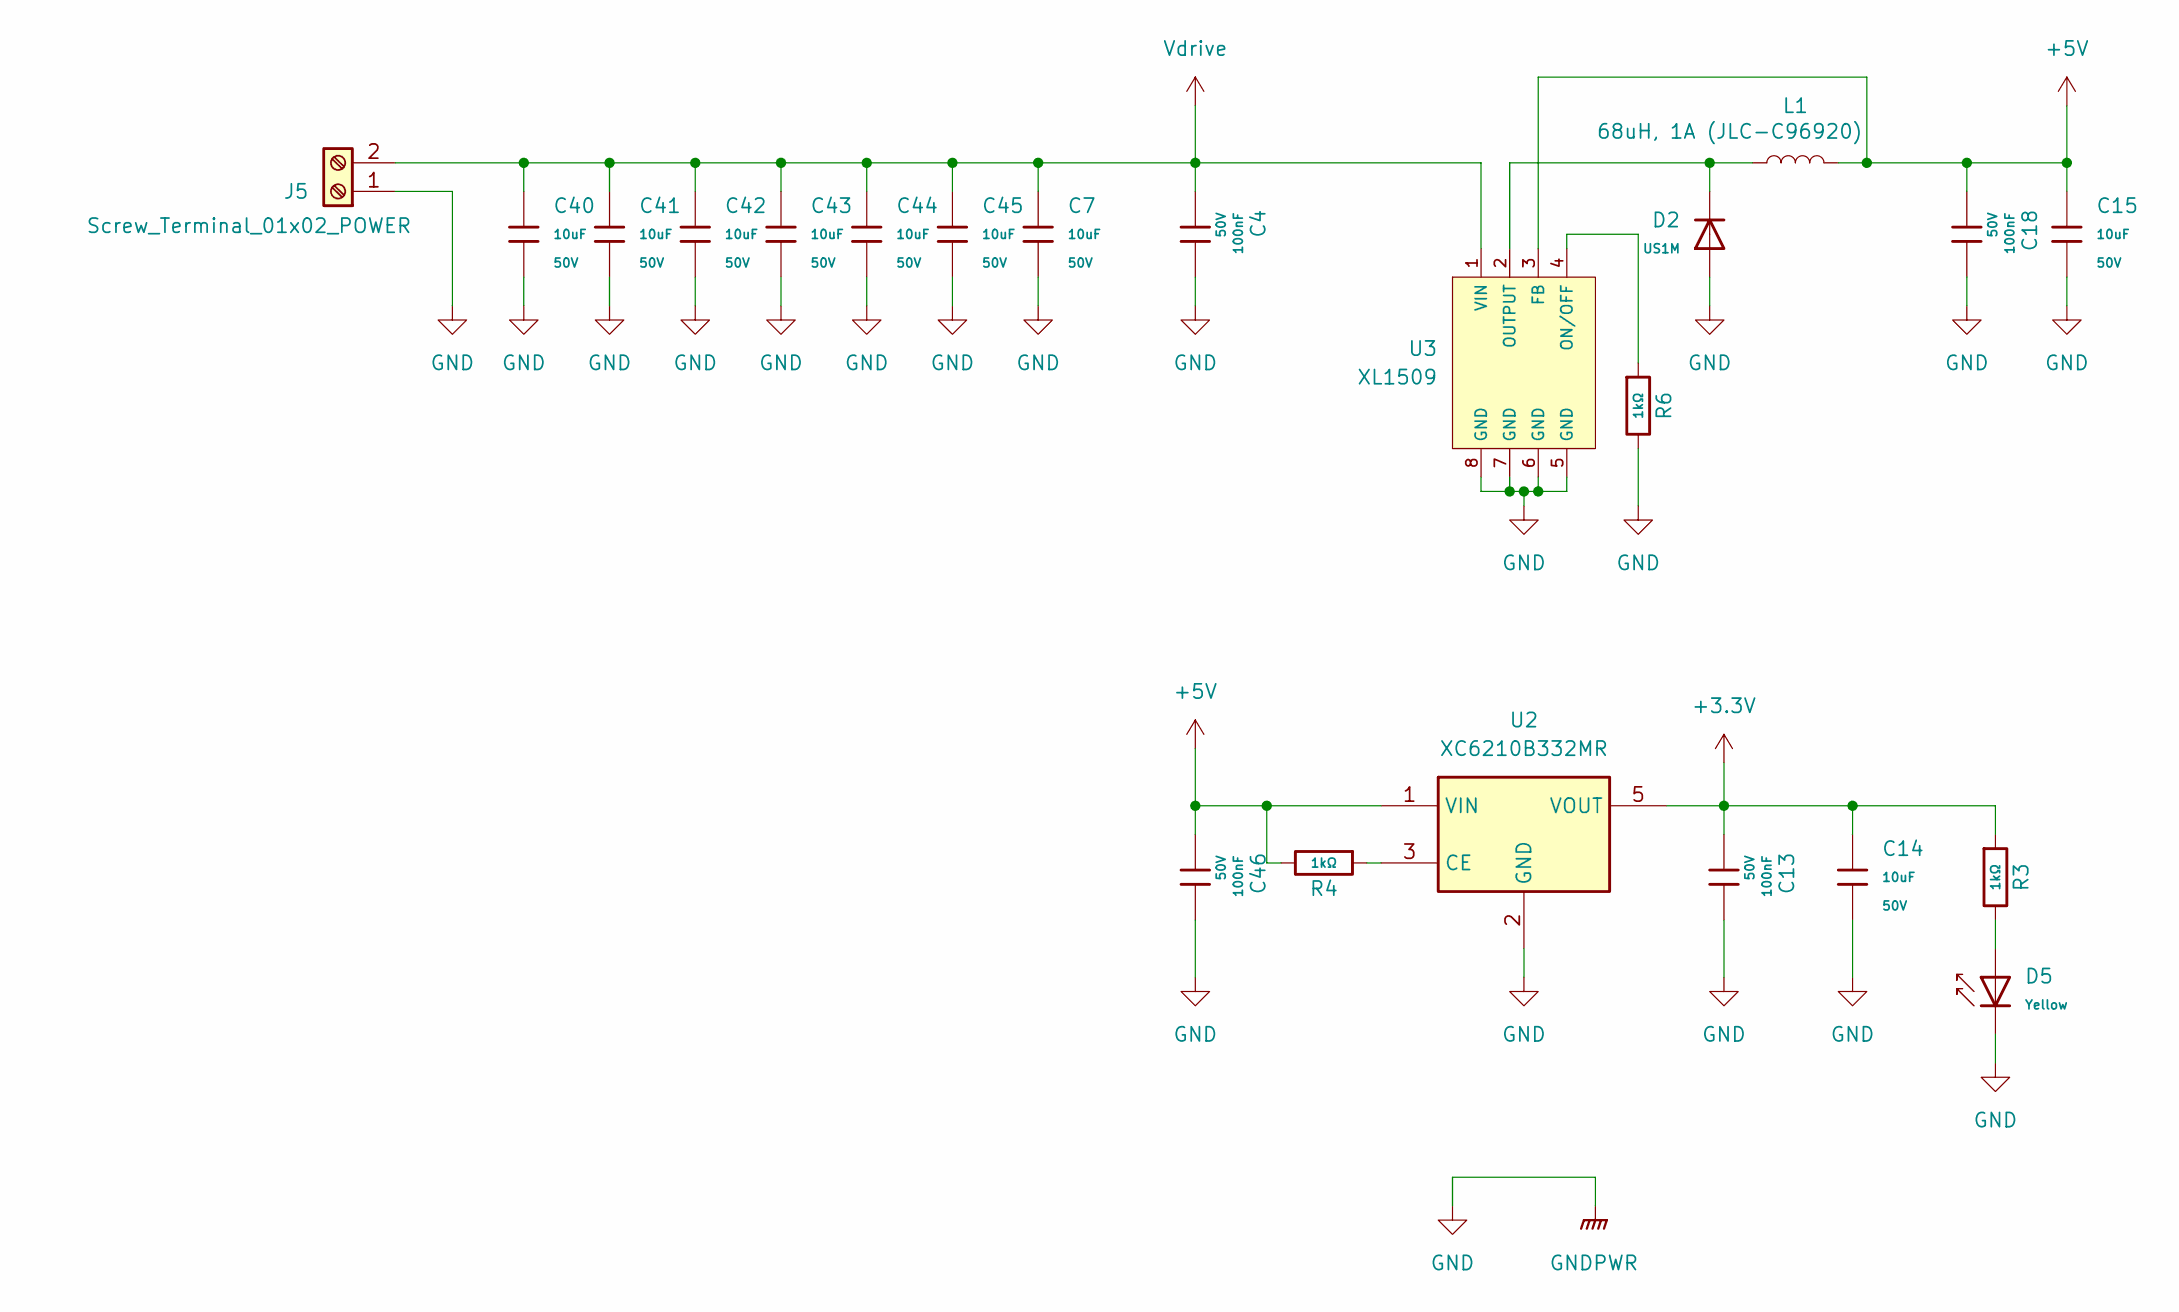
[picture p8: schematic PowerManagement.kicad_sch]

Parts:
C4, C13, C18, C46: 100nF; C_0603; Voltage Rated 50V; Tolerance ±10%; Part CC0603KRX7R9BB104; LCSC C14663
C7, C14, C15, C40, C41, C42, C43, C44, C45: 10uF; C_1206; Voltage Rated 50V; Tolerance ±10%; Part CL31A106KBHNNNE; LCSC C13585
D2: US1M; D_SMA; Forward Voltage (Vf@If) 1.65V@1A; Reverse Voltage (Vr) 1kV; Part US1M; LCSC C412437
D5: Yellow; D_0603; Forward Voltage (VF) 1.6V~2.6V; Part NCD0603Y2; LCSC C89811
J5: Screw_Terminal_01x02_POWER; PhoenixContact_MC_1,5_2-G-3.5_1x02_P3.50mm_Horizontal
L1: 68uH, 1A (JLC-C96920); L_Changjiang_FNR5020S
R3, R4, R6: 1kΩ; R_0603; Overload Voltage (Max) 75V; Tolerance ±1%; Part 0603WAF1001T5E; LCSC C21190
U2: XC6210B332MR; SOT-23-5
U3: XL1509; SOIC-8_L5.0-W4.0-P1.27-LS6.0-BL; Output Voltage 5V; Input Voltage 4.5V~40V; Part XL1509-5.0E1; LCSC C61063

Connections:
+3.3V: C13.1, C14.1, R3.1, U2.5 (VOUT); also elsewhere on the board
+5V: C15.1, C18.1, C46.1, L1.2, R4.2, U2.1 (VIN), U3.3 (FB); also elsewhere on the board
GND: C4.2, C7.2, C13.2, C14.2, C15.2, C18.2, C40.2, C41.2, C42.2, C43.2, C44.2, C45.2, C46.2, D2.2, D5.1, J5.1, R6.2, U2.2 (GND), U3.5 (GND), U3.6 (GND), U3.7 (GND), U3.8 (GND); also elsewhere on the board
unnamed: D5.2, R3.2
unnamed: R4.1, U2.3 (CE)
unnamed: R6.1, U3.4 (ON/OFF)
unnamed: D2.1, L1.1, U3.2 (OUTPUT)
Vdrive: C4.1, C7.1, C40.1, C41.1, C42.1, C43.1, C44.1, C45.1, J5.2, U3.1 (VIN); also elsewhere on the board

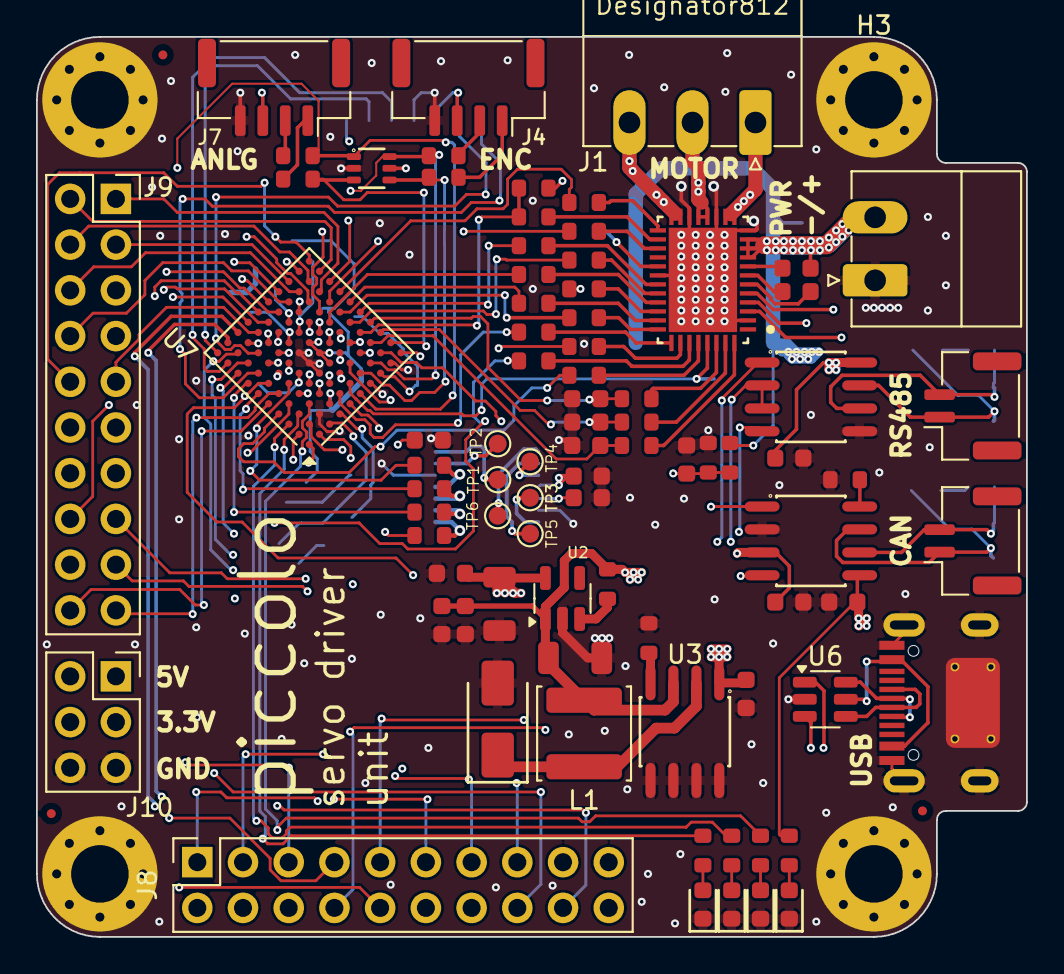
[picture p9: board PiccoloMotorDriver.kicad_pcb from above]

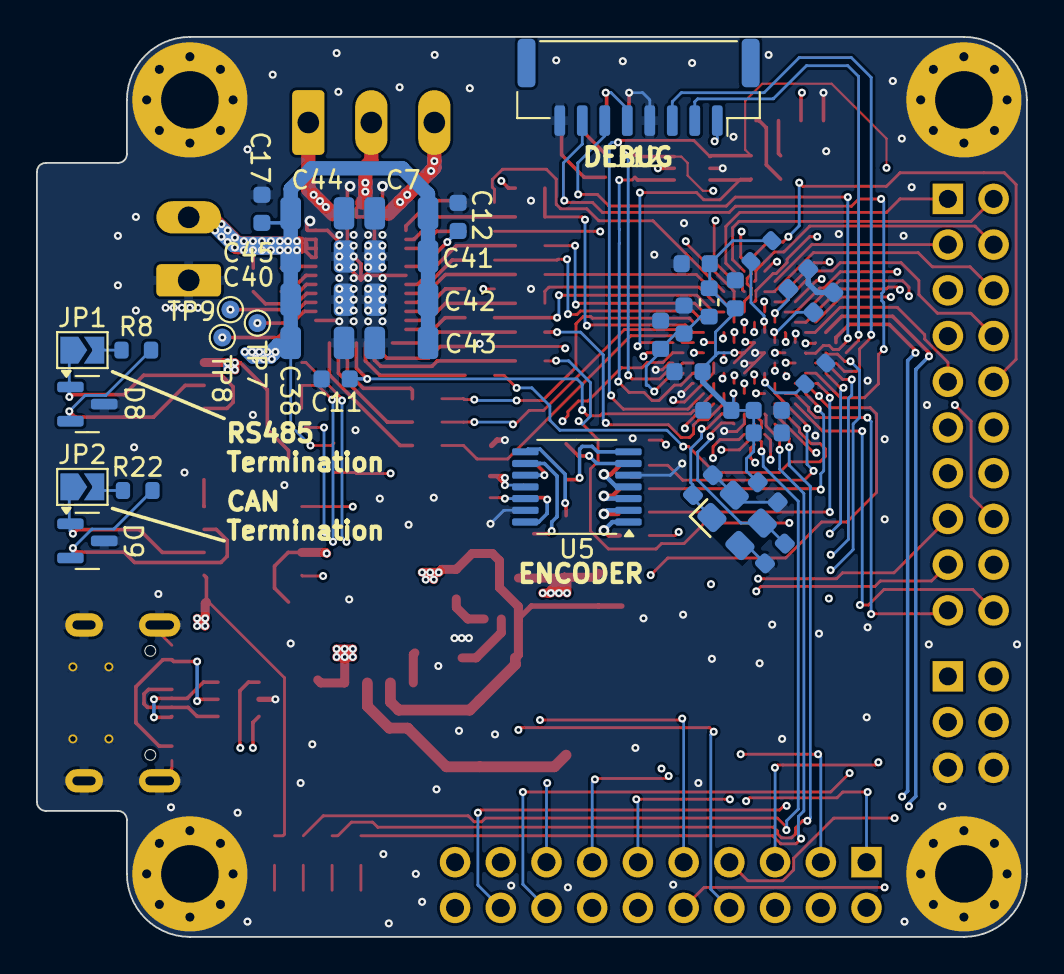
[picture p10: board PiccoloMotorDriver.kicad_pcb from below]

Board: 6 copper layers, 55.0 x 50.0 mm, 128 parts (39 on the bottom side), 149 nets.

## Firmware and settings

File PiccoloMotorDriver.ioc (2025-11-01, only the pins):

Mcu.UserName=STM32H723VGHx
PA0.Signal=S_TIM2_CH1_ETR
PA1.Signal=S_TIM2_CH2
PA11.Signal=USB_OTG_HS_DM
PA12.Signal=USB_OTG_HS_DP
PA13(JTMS/SWDIO).Signal=DEBUG_JTMS-SWDIO
PA14(JTCK/SWCLK).Signal=DEBUG_JTCK-SWCLK
PA15(JTDI).Signal=UART4_DE
PA2.GPIO_Label=v_bus
PA2.Signal=ADCx_INP14
PA3.GPIO_Label=ext0
PA3.Signal=ADCx_INP15
PA4.Signal=SPI1_NSS
PA6.GPIO_Label=phase_a
PA6.Signal=ADCx_INP3
PA7.GPIO_Label=phase_b
PA7.Signal=ADCx_INP7
PA8.Signal=RCC_MCO_1
PB1.GPIO_Label=phase_c
PB1.Signal=ADCx_INP5
PB3(JTDO/TRACESWO).Signal=SPI1_SCK
PB4(NJTRST).Signal=SPI1_MISO
PB5.Signal=SPI1_MOSI
PB6.Signal=I2C1_SCL
PB7.Signal=I2C1_SDA
PB8.Signal=FDCAN1_RX
PB9.Signal=SPI2_NSS
PC0.GPIO_Label=ext1
PC0.Signal=ADCx_INP10
PC1.GPIO_Label=drv_ref
PC1.Signal=ADCx_INP11
PC10.Signal=UART4_TX
PC11.Signal=UART4_RX
PC12.Signal=UART5_TX
PC2_C.Signal=SPI2_MISO
PC3_C.Signal=SPI2_MOSI
PC6.Signal=S_TIM3_CH1
PC7.Signal=S_TIM3_CH2
PC8.Signal=S_TIM3_CH3
PC9.Signal=S_TIM3_CH4
PD1.Signal=FDCAN1_TX
PD2.Signal=UART5_RX
PD3.Signal=SPI2_SCK
PE10.Signal=TIM1_CH2N
PE11.Signal=S_TIM1_CH2
PE12.Signal=TIM1_CH3N
PE13.Signal=S_TIM1_CH3
PE8.Signal=TIM1_CH1N
PE9.Signal=S_TIM1_CH1
PH0-OSC_IN.Signal=RCC_OSC_IN
PH1-OSC_OUT.Signal=RCC_OSC_OUT

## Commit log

2025-07-07 Add IO sub schematic, add communications
    [IO.kicad_sch, Mcu.kicad_sch, PiccoloMotorDriver.kicad_sch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]
2025-07-19 add IO, MCU, power sheets
    [DRV.kicad_sch, IO.kicad_sch, Mcu.kicad_sch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]
2025-07-21 Add encoder sheet
    [DRV.kicad_sch, Encoder.kicad_sch, IO.kicad_sch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]
2025-08-04 Add buck converter, add part of pinmap to mcu
    [DRV.kicad_sch, PowerManagement.kicad_sch]
2025-08-25 Add mcu connections
    [DRV.kicad_sch, Encoder.kicad_sch, IO.kicad_sch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]
2025-09-12 Added DRV layout
    [DRV.kicad_sch, Encoder.kicad_sch, IO.kicad_sch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]
2025-10-03 Re arrange connectors
    [Mcu.kicad_sch, PiccoloMotorDriver.kicad_pcb]
2025-10-06 updated mcu connections
    [DRV.kicad_sch, Encoder.kicad_sch, IO.kicad_sch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]
2025-10-09 layout placement
    [Encoder.kicad_sch, Mcu.kicad_sch, PiccoloMotorDriver.kicad_pcb]
2025-10-13 more layout
    [DRV.kicad_sch, Encoder.kicad_sch, PiccoloMotorDriver.kicad_pcb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]
2025-11-01 Reroute mcu lines, updated can, motor timer pins
    [DRV.kicad_sch, IO.kicad_sch, Mcu.kicad_sch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]
2025-12-07 Finished layout, pcba is being tested
    [Encoder.kicad_sch, IO.kicad_sch, Mcu.kicad_sch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]
